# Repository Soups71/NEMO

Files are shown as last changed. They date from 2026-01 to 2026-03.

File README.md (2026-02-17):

# NEMO Documentation

Welcome to NEMO—the **NMEA2000 Education and Maritime Operations Platform**.

NEMO is a research platform for exploring at maritime network security. It simulates sensors, sniffs traffic, and demonstrates just how easy you can mess with NMEA2000.

This platform focuses on lowering the bar for getting started with boat hacking. Typically to get started with boat hacking you would need thousands of dollars worth of equipment or a friend with a boat. Thankfully, with NEMO all you need is about 40 dollars.

## What's In Here

### Getting Your Feet Wet
1. **[Project Overview](Documentation/README.md)** - What this is and why boats need better security
2. **[Getting Started](Documentation/Getting_Started.md)** - From zero to flashing firmware
3. **[Operations Guide](Documentation/Operations_Guide.md)** - How to actually use the thing
4. **[FAQ](Documentation/FAQ.md)** - "Why doesn't X work?" answered here

### Understanding the Protocols
1. **[NMEA2000 Protocol](Documentation/NMEA2000.md)** - The marine standard for device communication

### Hardware
1. **[Design Reference](Documentation/PCB_Design.md)** - Schematics, layout, gerbers
2. **[3-D Printed Case](Documentation/Case_Design.md)** - Documentation on the case

### Software
9. **[Source Code Architecture](Documentation/Source_Code_Architecture.md)** - Deep dive into the firmware

### The Fun Part
10. **[Security Research & Attacks](Documentation/Attacks.md)** - How the attacks work and academic context

## Quick Start (TL;DR)

1. Get parts from [Hardware Guide](Documentation/PCB_Design.md)
2. Flash firmware via [Getting Started](Documentation/Getting_Started.md)
3. Learn the UI in [Operations Guide](Documentation/Operations_Guide.md)
4. Break Stuff
5. Profit!

## What This Is For

NEMO exists for:
- **Security researchers** exploring maritime vulnerabilities
- **Students** learning about CAN bus and protocol weaknesses
- **Industry folks** who want to see why NMEA2000 security matters

## Contributing

Found a bug? Got a cool feature idea? Open an issue or send a PR.

Contribution Ideas:
- New PGN support
- Bug fixes
- Documentation improvements

## Contact

Any questions or concerns regarding this project can be sent to nemo@jamescampbell.org

## Disclaimer

Released for educational and research purposes. Don't do crimes with it.

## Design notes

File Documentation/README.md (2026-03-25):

# Project Overview

## What's NEMO?

NEMO (NMEA2000 Education and Maritime Operations platform) is a Teensy 4.0-based research platform that lets you simulate a boat network in the palm of your hand. Security researchers, students, and maritime folks can poke around and see how NMEA2000 actually works - and more importantly, how it breaks.

The device can:

- Pretend to be multiple marine sensors on an NMEA2000 network
- Sniff traffic from other devices on the bus
- Impersonate other devices on the CAN network
- Perform DOS attack that prevents all devices from communicating on the BUS.

Simply stated, you can hack a boat without actually having a boat.

## Why Build This?

Modern boats are basically networked computers floating on water. Most information such as Navigation, autopilot messages, depth readings, and more are sent over NMEA2000. This connectivity is great for interoperability but terrible for security.

Here's the problem: NMEA2000 was designed in the 90s and released in 2001 when "network security" meant securing the boat physically. There's no authentication, no encryption, and any device on the bus can say whatever it wants. This was to make it a cheap and versitle platform that enabled communication across manufacture and device.

However, One bad device can spoof sensor readings, steal addresses, or flood the network with garbage.

This project exists to:

1. **Show people** how these attacks actually work
2. **Give researchers** a platform for developing defenses
3. **Raise awareness** that maritime cybersecurity is a real problem

## The Big Picture

Ships are critical infrastructure. Cargo vessels move 90% of global trade. Ferries carry millions of people. Fishing boats feed communities. 

Researchers have shown attacks that could:

- Display fake GPS positions, sending vessels off course
- Manipulate depth readings, potentially causing groundings
- Hide engine problems, masking critical failures
- Confuse autopilots with conflicting commands

By making these vulnerabilities tangible, we're trying to push the industry toward actually fixing this stuff.

## Architecture

NEMO runs on a Teensy 4.0 with two independent CAN interfaces:

- **CAN1**: Handles the transmission of information on to the bus. This includes three fake NMEA2000 sensors, spoofed NMEA messages, and carries out the DOS attacks.
- **CAN2** : Listen-only mode for monitoring the network.

This dual-bus design lets you both participate in AND watch the network at the same time. Hook two NEMO devices together and one can play victim while the other demonstrates attacks.

For the full code breakdown, see [Source Code Architecture](Source_Code_Architecture.md).

### User Interface

The UI runs on a 1.3" SH1106 OLED (128x64 pixels) with four buttons:
- **Up/Down**: Navigate menus, change values
- **Left**: Go back, cancel
- **Right**: Select, confirm

Three 10K pots provide analog input for:
- Controlling fake sensor values
- Adjusting attack parameters on the fly

### What It Can Do

**Sensor Simulation** (13 types):

- Navigation: Heading, Depth, Speed, Position, COG/SOG
- Engine: RPM, Rudder Angle
- Environment: Wind, Temperature, Pressure, Humidity
- Systems: Battery Voltage, Tank Level

**Network Monitoring**:

- Auto-discovery via ISO Address Claim and Product Info
- Real-time PGN parsing and display
- Heartbeat-based stale device detection
- CAN Data Dump through serial interface

**Attack Demonstrations**:

- DOS Attack (Address Claim Takeover)
- Impersonation Attack (Data Spoofing with field locking)

**Data Dump**:

- All data that is received by the device is dumped out over the Serial Console in the standard CANDUMP format.
- This can then be processed by `candump2analyzer` and `analyzer` procided by the CANBOAT organization. [CANBOAT](https://github.com/canboat/canboat)

## Hardware Design

The custom PCB puts everything together. Check [PCB Design Reference](PCB_Design.md) for:

- Complete schematics
- Part specs and numbers
- Layout considerations
- Gerbers for manufacturing

## Credit

This project would not be possible without the amazing work put together by [Timo Lappalainen](https://github.com/ttlappalainen) and the people over at the [CANBOAT Project](https://github.com/canboat). They both have put in a ton of effort that has enabled this project. Please go check out their work if you're interested in Boat Hacking and NMEA2000.

## Where To Go From Here

- Learn about [NMEA2000](NMEA2000.md) protocols
- Check the [Hardware Guide](PCB_Design.md) for build instructions
- Follow [Getting Started](Getting_Started.md) to flash the firmware
- Dig into the [Source Code Architecture](Source_Code_Architecture.md) if you want to hack on it

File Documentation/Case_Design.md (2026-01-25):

# Case Design Reference

Apart from the electrical hardware, I also created a 3-D printed case for the PCB. This was to minimize the chance of accidental shorts when setting the device down.

The design files for this can be found in the `NEMO/Case_Design/*`

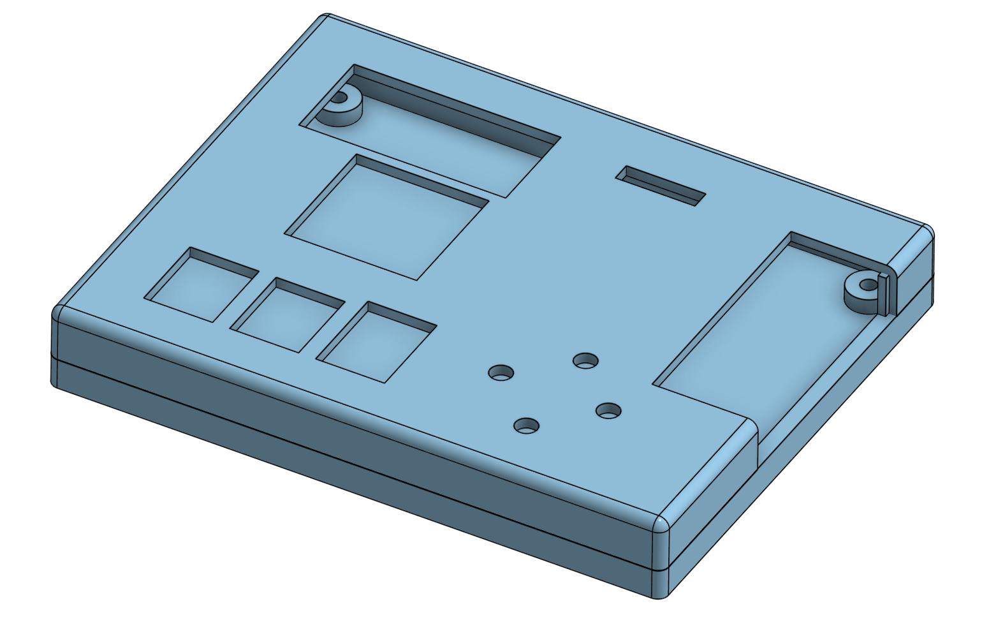
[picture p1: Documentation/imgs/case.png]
Case Design


## Files

### **Bottom.stl**

The bottom part of the case

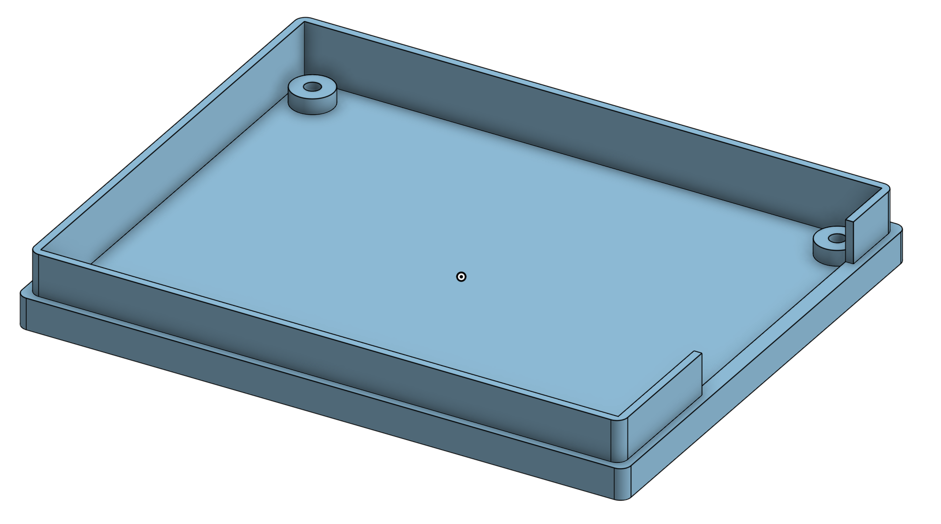
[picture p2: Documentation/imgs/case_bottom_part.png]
Bottom Part of the Case


### **Top.stl**

The top part of the case

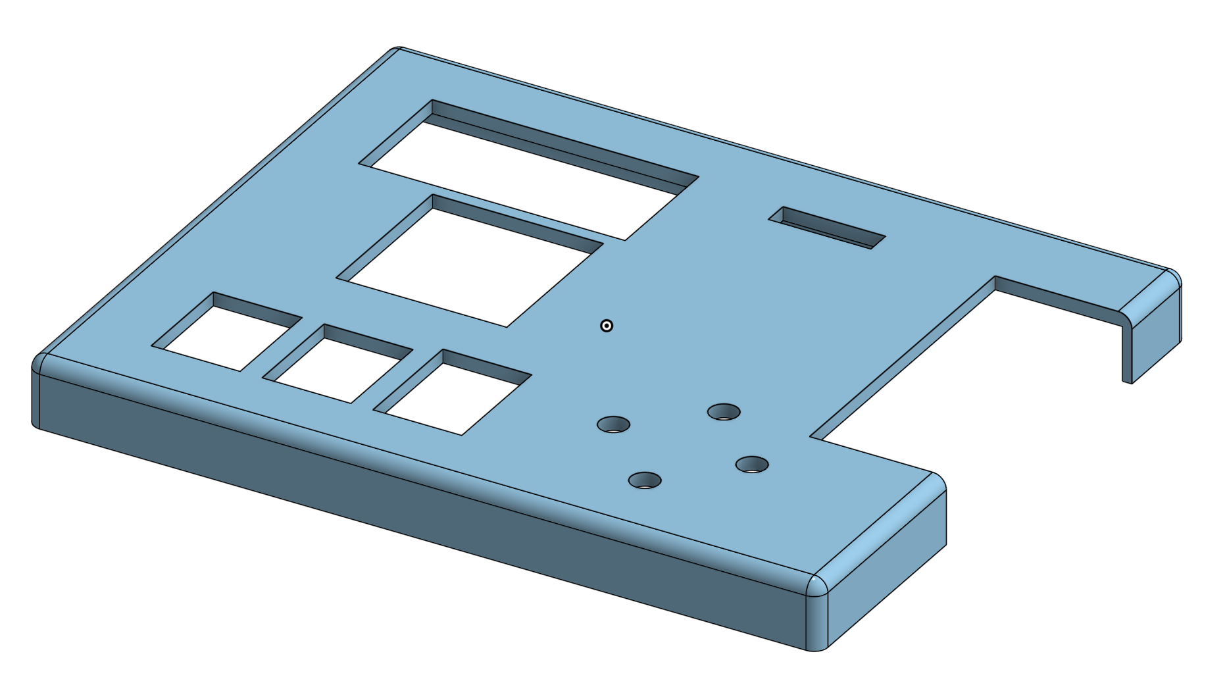
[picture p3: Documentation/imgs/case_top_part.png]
Top Part of the Case


## Printing

I printed both the top and bottom on my P1S and they turned out great with PLA+.

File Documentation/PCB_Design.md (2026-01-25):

# PCB Design Reference

So you want to build your own NEMO? Cool. This doc covers everything about the PCB including what's on it, why it's there, and how to not screw up the assembly.

If you don't want to go through the hassle of getting the PCB ordered or you don't want to use a Breadboard to build out the schematic you're in luck!

Email me at nemo@jamescampbell.org with "Board Request" as the subject and I will work with you to get a board shipped out.

## What We're Building

The NEMO PCB is a Teensy 4.0 shield that adds:
- Dual CAN bus interfaces (one for talking, one for snooping)
- OLED display for the UI
- D-pad buttons for navigation
- Three pots for controlling values
- NMEA2000 connector to plug into real networks

All the design files are KiCad 9.0 format in the `PCB/` folder.

## PCB Design

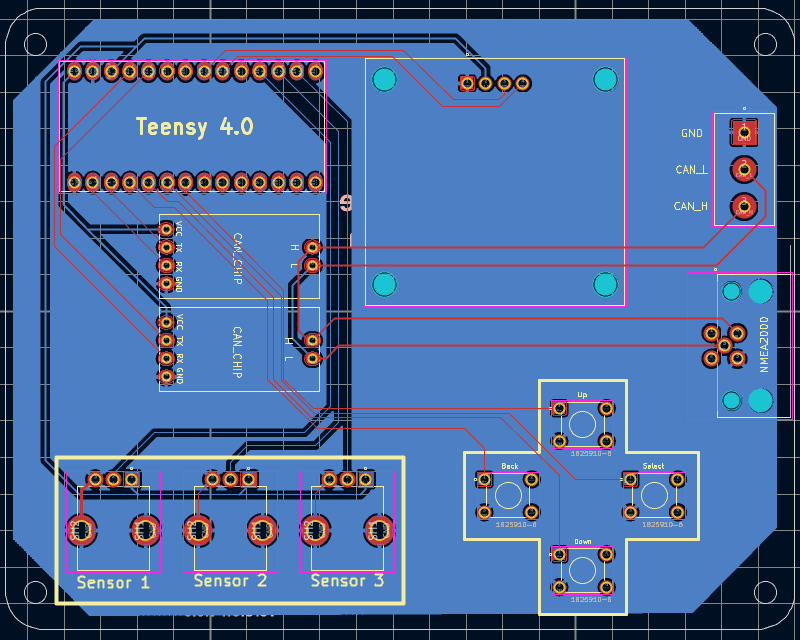
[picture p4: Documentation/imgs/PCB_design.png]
PCB Design


## Schematic

If you don't want to build the PCB from scratch, you can just use the schematic to build your own version.

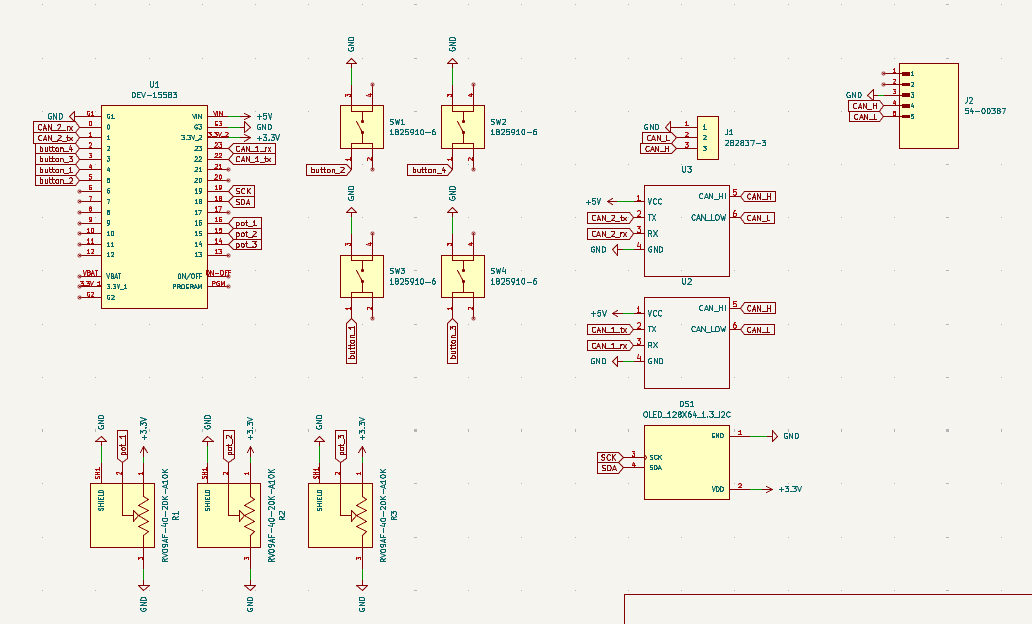
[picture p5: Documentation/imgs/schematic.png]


## Parts List

### Links to Amazon

Below are the links to the parts I used when building my prototypes and ultimately my final board. There are definetly cheaper options, but milage may vary

| | |
|-|-|
|Teensy 4.0|https://www.sparkfun.com/teensy-4-0.html|
|SH1106 Display|https://www.amazon.com/dp/B0C3L7N917|
|TJA1050|https://www.amazon.com/dp/B0C7ZBDG4B|
|10k Potentiometer| https://www.amazon.com/dp/B0DN1DHWLR|
|Buttons|https://www.amazon.com/dp/B07HB12V9Q|
|3 Screw Terminal|https://www.amazon.com/dp/B08PQG24YK|
|NMEA2000 Terminal|https://us.rs-online.com/product/rs-pro/2017209/72310500/|

**I do not guarentee quality from a supplier. These are just what worked for me.**

### The Brain: Teensy 4.0

| | |
|-|-|
| Part | SparkFun DEV-15583 |
| Chip | NXP iMXRT1062, ARM Cortex-M7 @ 600MHz |
| CAN | 2x FlexCAN controllers (this is why I picked it) |

**Pin Usage**:

| Pin | What | Why |
|-----|---|-----|
| 0 | CAN2_TX | Monitor bus TX (not really used in listen-only) |
| 1 | CAN2_RX | Monitor bus RX |
| 2 | button_1 | Left/Back |
| 3 | button_2 | Down |
| 4 | button_4 | Right/Select |
| 5 | button_3 | Up |
| 14 (A0) | pot_3 | Sensor 3 value |
| 15 (A1) | pot_2 | Sensor 2 value |
| 16 (A2) | pot_1 | Sensor 1 value |
| 18 | SDA | I2C data to display |
| 19 | SCL | I2C clock to display |
| 22 | CAN1_TX | Attack/transmit bus TX |
| 23 | CAN1_RX | Attack/transmit bus RX |

### CAN Transceivers

You need two of these - one for each CAN bus.

| | |
|-|-|
| Options | TJA1050 |
| Voltage | **5V** - this is important! |

**Wiring**:

| Pin | Function |
|-----|---|
| 1 | TXD (from Teensy) |
| 2 | GND |
| 3 | VCC (5V) |
| 4 | RXD (to Teensy) |
| 5 | CANL |
| 6 | CANH |

U2 = CAN1 (the attack bus)
U3 = CAN2 (the sniffer bus)

### Display

Just a 4-pin header: GND, VCC, SCL, SDA. Most modules have pull-ups built in.

Watch out! Some cheap displays have different pinouts. I made a mistake on the first prototype and burnt out a teensy. **Be Careful**

### Buttons

These are the D-pad:
- SW1 = Up (Pin 5)
- SW2 = Down (Pin 3)
- SW3 = Left (Pin 2)
- SW4 = Right (Pin 4)

Active low - one pin to GPIO, one pin to ground. Firmware enables internal pullups.

### Pots (R1-R3)

Wiring:
- Pin 1 (CCW end): GND
- Pin 2 (wiper): Teensy analog input
- Pin 3 (CW end): 3.3V

These control the sensor values and attack parameters. Turn the knob, change the data.

### NMEA2000 Connector

| | |
|-|-|
| Part | RS PRO 2017209 |
| Mates with | Standard NMEA2000 cables |

**Pinout** (standard NMEA2000):

| Pin | Color | Function |
|-----|---|---|
| 1 | White | Shield/GND |
| 2 | Blue | CAN_L |
| 3 | Black | GND |
| 4 | Red | +12V (optional power input) |
| 5 | White | CAN_H |

This connects to CAN2 (the sniffer). You can plug NEMO right into a boat's backbone.

### Terminal Block 

Alternative CAN connection for bench testing. CAN_H, CAN_L, GND.

## Power

### Where It Comes From

**USB** 
- Plug USB into the Teensy
- Teensy's regulator provides voltage to everything
- Simple, good for development

Okay, I get it. Powering the device via the NMEA2000 bus would be cool. There is probably a version 2 coming down the line with that capability. However, I wanted to make this project as beginner friendly as possible and built with only readily accessible consumer parts. As a result, it was a conscience decision not to connect power to the bus. I don't need someone blowing out their USB port because they left it plugged in while they also had it connected to the NMEA2000 network.

**CAN1**: This is where NEMO transmits messages. Fake sensors broadcast here, attacks go here.

**CAN2**: Listen-only mode. NEMO watches the network without participating in arbitration.

## Resources

- [Teensy 4.0 Pinout](https://www.pjrc.com/teensy/pinout.html)
- [NMEA2000 Physical Layer](https://www.nmea.org/)
- [KiCad Docs](https://docs.kicad.org/)

That's the hardware. Build it, flash it, plug it into a boat network, and have fun.

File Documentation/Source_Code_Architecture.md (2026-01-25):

# Source Code Architecture

Welcome to the guts of NEMO. This doc breaks down how the firmware works, what each module does, and where to find stuff when you want to hack on it yourself.

## Project Structure

We're using PlatformIO because fighting with Arduino IDE dependency hell isn't fun for anyone.

## Build Setup

**File**: `SRC/platformio.ini`

Nothing fancy here:

```ini
[env:teensy40]
platform = teensy
board = teensy40
framework = arduino
```

### Dependencies

| Library | What it does |
|---|---|
| `U8g2` | Talks to the OLED |
| `Adafruit SSD1306` | More display stuff |
| `Adafruit GFX Library` | Drawing primitives |
| `VEGA_SH1106` | Our specific display controller |
| `NMEA2000` | The protocol stack |
| `NMEA2000_Teensyx` | Teensy CAN driver |

The NMEA2000 libs are forked versions for stability. 

## The Main Loop (`main.cpp`)

**File**: `SRC/src/main.cpp`

### Pin Mapping

```cpp
// Pots for controlling values
#define SENSOR_1 16    // A2 - Pot R1
#define SENSOR_2 15    // A1 - Pot R2
#define SENSOR_3 14    // A0 - Pot R3

// D-pad buttons (active-low, pullups enabled)
#define BUTTON_UP 5
#define BUTTON_DOWN 3
#define BUTTON_LEFT 2
#define BUTTON_RIGHT 4
```

### The Dual-Bus Trick

The Teensy 4.0 has two easily accessible CAN controllers:

```cpp
tNMEA2000_Teensyx NMEA2000_CAN1(tNMEA2000_Teensyx::CAN1);  // TX bus
tNMEA2000_Teensyx NMEA2000_CAN2(tNMEA2000_Teensyx::CAN2);  // Sniffer bus
```

**Why two buses?**

- **CAN1**: This is transmits all messages on the bus, including three fake sensors, plus all the attack traffic.
- **CAN2** : Listen-only mode. NEMO sniffs everything without participating in arbitration - nobody knows we're watching.

You can be on the network AND monitor it at the same time. Pretty useful for seeing the effects of your attacks in real-time.

### Multi-Device Set-Up

```cpp
#define DEVICE_MANUFACTURER_CODE 2046  // Fake Manufacture Code by default
#define DEVICE_CLASS 25                 // "Inter/Intranetwork Device"
#define NUM_DEVICES 3                   // Three fake devices
```

Each sensor is a fully independent NMEA2000 device with its own:
- Source address
- 64-bit NAME 
- Product info (model name, serial, version)
- Heartbeat

### Boot Sequence

When `setup()` runs:

1. Serial at 115200 for debug output
2. Configure all the pins
3. Spin up CAN1 with three devices starting at address 22
4. Spin up CAN2 in sniff mode with a fat 2048-frame buffer
5. Init the OLED
6. Create the monitor, attack controller, and menu controller
7. Show the main menu

### Debug Output

Everything received on CAN2 gets dumped in `candump` format:

```
can1  09F80106   [8]  00 00 23 FF FF FF FF FF
can1  09F11001   [8]  01 18 27 4A 00 FF 64 00
```

Hook up a terminal at 115200 baud and you can pipe this to analysis tools. Fast-packet messages get reassembled so you see the original frames.

## Constants (`constants.h`)

**File**: `SRC/include/constants.h`

This is where all the tunables live. Mess with these to change behavior without touching logic.

### Debug Flag

```cpp
#define DEBUG false  // true = verbose, false = candump only
```

### Timing

```cpp
STALE_TIMEOUT_MS = 60000   // Remove devices after 1 min silence
SCROLL_DELAY_MS = 400      // Text scroll speed
MAX_IMP_FIELDS = 16        // Max fields you can lock during impersonate
```

## Sensor Types

13 different sensors you can simulate:

| # | Type | PGN | Range |
|---|---|-----|---|
| 0 | Engine RPM | 127488 | 0-6000 |
| 1 | Water Depth | 128267 | 0-100m |
| 2 | Heading | 127250 | 0-360° |
| 3 | Speed | 128259 | 0-20 knots |
| 4 | Rudder | 127245 | ±45° |
| 5 | Wind Speed | 130306 | 0-50 m/s |
| 6 | Wind Angle | 130306 | 0-360° |
| 7 | Water Temp | 130311 | -5 to 40°C |
| 8 | Outside Temp | 130310 | -20 to 50°C |
| 9 | Pressure | 130314 | 80-110 kPa |
| 10 | Humidity | 130313 | 0-100% |
| 11 | Battery | 127508 | 0-30V |
| 12 | Tank Level | 127505 | 0-100% |

## Fake Manufacturer IDs

Want to pretend you're Garmin? Raymarine?

| Manufacturer | Code |
|---|---|
| Garmin | 229 |
| Raymarine | 1851 |
| Simrad | 1857 |
| Navico | 275 |
| Lowrance | 140 |
| Furuno | 1855 |
| B&G | 381 |
| Mercury | 144 |
| Yamaha | 1862 |
| Volvo Penta | 174 |
| Maretron | 137 |

## Spoofable PGNs

28 message types NEMO can impersonate - basically anything useful for navigation, engine monitoring, or environmental data:

```cpp
127245 (Rudder), 127250 (Heading), 127251 (Rate of Turn),
127252 (Heave), 127257 (Attitude), 127258 (Mag Variation),
127488 (Engine Rapid), 127489 (Engine Dynamic), 127493 (Transmission),
127497 (Trip Fuel), 127505 (Fluid Level), 127506 (DC Status),
127507 (Charger), 127508 (Battery), 128000 (Leeway),
128259 (Speed Water), 128267 (Depth), 129025 (Position),
129026 (COG/SOG), 130306 (Wind), 130310-130316 (Environmental),
130576 (Trim Tab), 130577 (Direction)
```

## Debugging Tips

Serial output at 115200 shows all sniffed traffic in candump format. Pipe it to your favorite analysis tools.

| Problem | Likely Cause | Fix |
|---|---|-----|
| No serial | Wrong baud | Set to 115200 |
| Black screen | I2C wiring | Check SDA(18), SCL(19) |
| No CAN traffic | Missing termination | Add 120 ohm resistors |
| Sensors not broadcasting | Inactive | Enable in Configure menu |

That's the architecture. Go hack some boats (in a lab enviroment, with your own equipment, obviously).

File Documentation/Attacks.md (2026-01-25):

# Security Research and Attack Demos

This doc covers the attacks NEMO can demonstrate, how they work under the hood, and what they would mean on a real boat.

## The Two Attacks

NEMO implements two attack categories:

1. **DOS Attack** - Kicks all devices off the network
2. **Impersonation Attack** - Spoofs valid sensors on the network by modifying fields certain fields and leaving others alone

Both exploit fundamental weaknesses in how NMEA2000 trusts devices on the bus - inherited straight from CAN and ISO 11783.

## DOS Attack

### The Gist

Every NMEA2000 device has a 64-bit NAME that determines its priority in address fights. When two devices claim the same address, the one with the numerically lower NAME wins. Loser has to find a new address or go dark.

NEMO's attack exploits this by:

1. **Building a high-priority NAME** with artificially low values
2. **Claiming all possible addresses** with the superior NAME. This forces all devices to find a new address.
3. **Continuosly override address claims** of the other devices as they try to find a new valid address.

The attack NAME uses:
- Unique Number: 0 (lowest possible)
- Manufacturer Code: 0 (lowest possible)
- Priority: 0 (Highest priority)
- Everything else minimized

This creates a NAME that beats basically any real device.

### What Happens

When a device loses its address claim, it has to either:
- Find an unclaimed address
- Go offline

On an actual boat this could mean:
- GPS/chartplotter stops updating
- Depth sounder data disappears
- Engine monitoring goes away
- Autopilot loses its inputs

## Impersonation Attack (Data Spoofing)

### The Gist

NMEA2000 has zero authentication. Any device can send any PGN from any source address. The impersonation attack:

1. **Monitors traffic** to see legitimate sensor data
2. **Picks a target** device and the PGNs it transmits
3. **Replays modified messages** with our own values
4. **Uses the potentiometer** to control spoofed values in real time

NEMO copies the message structure but swaps in whatever values the user wants.

### Supported PGNs

NEMO can spoof these:

**Navigation:**
- 127250: Vessel Heading
- 129025: Position (Lat/Long)
- 129026: COG/SOG
- 128267: Water Depth

**Engine & Systems:**
- 127488: Engine RPM
- 127489: Engine Parameters (oil pressure, temp, etc.)
- 127505: Fluid Level (fuel tanks)
- 127508: Battery Status

**Environmental:**
- 130306: Wind Data
- 130310/130311: Environmental Parameters
- 130312: Temperature
- 130314: Pressure

### What Could Go Wrong

**Fake Position Data**
Spoofing PGN 129025 (Position) or 129026 (COG/SOG):
- Chartplotter shows wrong location
- AIS broadcasts lies to other vessels
- Autopilot navigates to the wrong place
- ECDIS route monitoring fails

**Manipulated Depth**
Spoofing PGN 128267 (Water Depth):
- Show deeper water than reality → grounding risk
- Show shallower water → unnecessary course changes
- Disable shallow water alarms

**False Engine Data**
Spoofing engine PGNs:
- Hide overheating or low oil pressure
- Show fake RPM
- Mask critical failures until it's too late

**Wrong Wind Data**
Spoofing PGN 130306 (Wind Data):
- Mess up sail trim systems
- Make autopilot wind-steering go haywire
- Mislead crew about conditions

### Why Not Just Spoof Another Sensor?

Devices such as displays and autopilots often require the configuration of devices to ensure that the information displayed is from the correct device.

This means that if an attacker were to just send information on the bus the chance that it would actually be displayed by smart displays is actually pretty low.

By spoofing a device that is alreay on the network, it increases the chances that our modified values will actually appear on displays and be processed by autopilots.

-- 

## References

These attacks are not novel and have been well documented in other fields. Here are some articles that aided in the design of the attacks.

https://www.can-cia.org/fileadmin/cia/documents/publications/cnlm/june_2023/cnlm_23-2_p28_j1939-based_networks_vulnerability_to_address_claim_hunter_cyberattack_chri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

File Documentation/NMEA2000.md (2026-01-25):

# NMEA2000 Protocol

## What's NMEA2000?

NMEA2000 (also written N2K) is the communication standard that boats use for connecting sensors, displays, and control systems. Think of it as the marine equivalent of your car's internal network - it lets the GPS talk to the chartplotter, the depth sounder share data with the autopilot, and the engine computer report status to the helm display.

The protocol comes from the National Marine Electronics Association (NMEA), the same organization behind the older NMEA 0183 standard.

## NMEA 0183 vs NMEA2000

If you've messed with marine electronics before, you probably hit NMEA 0183 first. It spits out human-readable sentences like:

```
$GPGGA,123519,4807.038,N,01131.000,E,1,08,0.9,545.4,M,47.0,M,,*47
```

0183 worked fine for decades, but it's got issues:
- Slow (4,800 baud, sometimes 38,400)
- Point-to-point wiring
- No standard connector
- ASCII text only

NMEA2000 fixes these:

| Thing | NMEA 0183 | NMEA2000 |
|---|---|---|
| Speed | 4,800-38,400 baud | 250,000 baud |
| Topology | Point-to-point | Multi-drop bus |
| Connector | Whatever | Standardized 5-pin connector |
| Format | ASCII text | Binary |
| Power | Separate | On the network cable |

## Under the Hood

NMEA2000 is built on existing standards:

1. **Physical Layer**: CAN bus at 250 kbps
2. **Data Link Layer**: ISO 11783-3 (also used in tractors, fun fact)
3. **Network Layer**: ISO 11783-5 for address management
4. **Application Layer**: NMEA's Parameter Group Numbers (PGNs)

This means NMEA2000 devices use off-the-shelf CAN chips. The interesting stuff is in the protocol on top.

## Addressing and Identity

Every device needs a unique source address (0-251). But addresses aren't hardcoded - NMEA2000 uses dynamic claiming based on ISO 11783.

Each device has a 64-bit NAME that uniquely identifies it:

| Field | Bits | What |
|---|---|---|
| Identity Number | 21 | Serial number from manufacturer |
| Manufacturer Code | 11 | Assigned by NMEA |
| Device Instance | 3 | Distinguishes multiples of same device |
| Device Function | 8 | What it does |
| Device Class | 7 | Category |
| System Instance | 4 | For complex installs |
| Industry Group | 3 | Marine = 4 |
| Self-Configurable | 1 | Always 1 for N2K |

When a device powers on, it broadcasts its NAME to claim an address using the 60928 PGN. If two devices want the same address, the one with the numerically lower NAME wins. Loser picks a different address.

**This is the key to the DOS attack**: NAME determines priority. A device with a lower NAME can kick any higher-NAME device off its address.

## Parameter Group Numbers (PGNs)

Data in NMEA2000 comes in Parameter Groups, each with a PGN. Think of PGNs as message types. Common ones:

| PGN | Name | What It Carries |
|-----|---|---|
| 60928 | ISO Address Claim | Device identity broadcast |
| 126992 | System Time | Date and time |
| 127250 | Vessel Heading | Compass heading |
| 127488 | Engine Parameters, Rapid | RPM, boost pressure |
| 128259 | Speed, Water Referenced | Speed through water |
| 128267 | Water Depth | Depth below transducer |
| 129025 | Position, Rapid Update | Lat/long |
| 129026 | COG & SOG | Course and speed over ground |
| 130306 | Wind Data | Wind speed and angle |

NMEA sells the complete PGN database, but many common ones are documented through reverse engineering and the open source library community.

Shoutout to CANBOAT project for doing a ton of the heavy lifting. Check them out here: [CANBOAT](https://canboat.github.io/canboat/canboat.html)

## Message Structure

NMEA2000 packs data into CAN frames. The 29-bit identifier encodes:

- Priority (3 bits): 0-7, lower = higher priority
- PGN (18 bits): The parameter group number
- Source Address (8 bits): Who sent it

Data fields use standardized formats:
- Temperatures in 0.01 Kelvin
- Angles in radians × 10,000
- Distances in 0.01 meters
- Speed in 0.01 m/s

The library handles conversions, but knowing raw formats helps when analyzing traffic.

## Fast Packets

Some data doesn't fit in 8 bytes. For these, NMEA2000 uses "fast packet" messages spanning multiple frames. 

Fast packets include sequence and frame counters so receivers can reassemble the complete message.

## Network Layout

A typical network consists of all of devices connecting to one backbone. 

The backbone is a trunk cable with T-connectors for each device. Termination resistors cap each end. Power can flow through the network or come in separately for hungry devices.

Max length is around 100 meters for the backbone with 6-meter drops.

## The Security Problem

NMEA2000 inherits CAN's trust model: any device can send any message. Combined with address claiming, this creates attack vectors:

1. **Spoofing**: Send fake sensor data (false GPS, wrong depth)
2. **Denial of Service**: Flood the bus with high-priority garbage
3. **Impersonation**: Pretend to be a specific device

There's no cryptographic authentication. A device can't verify that a message actually came from the claimed source. No integrity protection beyond basic CRC error checking.

This wasn't an oversight - it reflects the threat model of the 90s when the protocol was designed. "Network security" meant physical access control: only trusted devices get plugged in.

That assumption increasingly fails as:
- WiFi gateways get added for monitoring
- USB and Bluetooth adapters provide diagnostic access
- Aftermarket devices from sketchy sources get installed
- Charter boats have random users

## NEMO Implementation

NEMO implements NMEA2000 using the Teensy 4.0's dual FlexCAN controllers and the NMEA2000 library. Here's how it all fits together.

### Multi-Device Mode

NEMO simulates up to three independent NMEA2000 devices on CAN1. Each gets its own:
- Source address (starting at 22)
- Device NAME (64-bit unique ID)
- Product information
- Heartbeat interval

### Supported PGNs

NEMO generates and parses these (defined in `constants.h`):

| PGN | Name | NEMO Use |
|-----|---|---|
| 60928 | ISO Address Claim | Identity, attack target |
| 126993 | Heartbeat | Device presence |
| 126996 | Product Information | Name extraction |
| 127245 | Rudder | Simulate/spoof |
| 127250 | Vessel Heading | Simulate/spoof |
| 127488 | Engine RPM | Simulate/spoof |
| 127489 | Engine Parameters | Spoof only |
| 127505 | Fluid Level | Simulate/spoof |
| 127508 | Battery Status | Simulate/spoof |
| 128259 | Speed, Water | Simulate/spoof |
| 128267 | Water Depth | Simulate/spoof |
| 129025 | Position | Spoof only |
| 129026 | COG & SOG | Spoof only |
| 130306 | Wind Data | Simulate/spoof |
| 130310-130316 | Environmental | Simulate/spoof |

For the full code breakdown, see [Source Code Architecture](Source_Code_Architecture.md).

## More Reading

- [NMEA 2000 Explained](https://www.nmea.org/nmea-2000.html) - Official NMEA overview
- [OpenSkipper NMEA2000 Documentation](http://openskipper.org/) - Open source notes
- [CANboat](https://github.com/canboat/canboat) - PGN docs and analysis tools
- [NMEA2000 Library](https://github.com/ttlappalainen/NMEA2000) - The NMEA2000 Library used
- [Full NMEA2000 Breakdown](https://www.csselectronics.com/pages/nmea-2000-n2k-intro-tutorial)

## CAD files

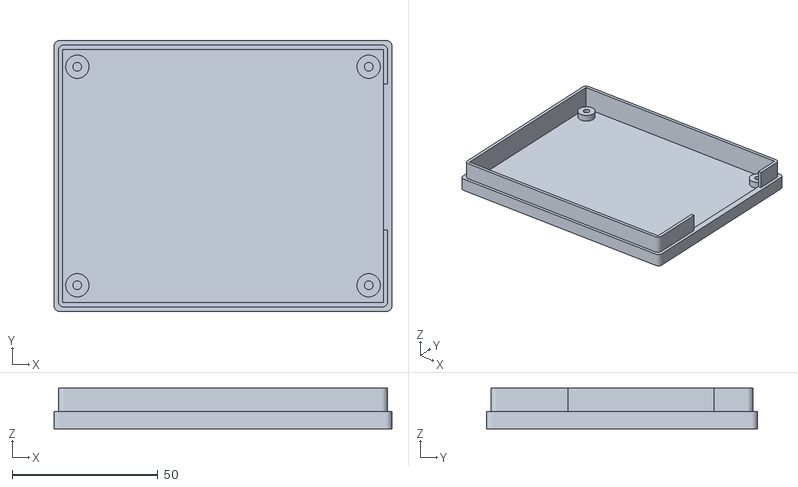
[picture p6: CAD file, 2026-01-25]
Case_Design/Bottom.stl
116.0 x 93.0 x 14.0

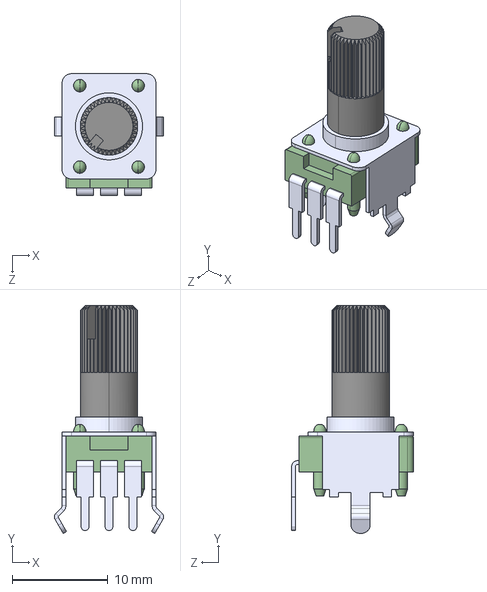
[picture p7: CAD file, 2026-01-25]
PCB/RV09AF-40-20K-A10K/RV09AF-40-20K-A10K.step
11.4 x 23.8 x 12.7 mm

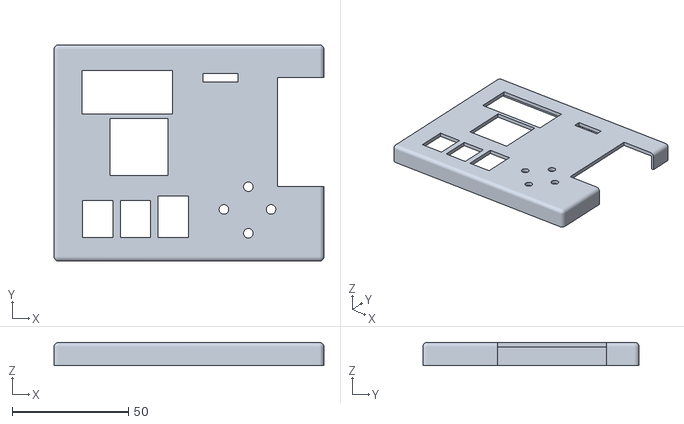
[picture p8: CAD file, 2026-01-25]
Case_Design/Top.stl
116.0 x 93.0 x 10.0

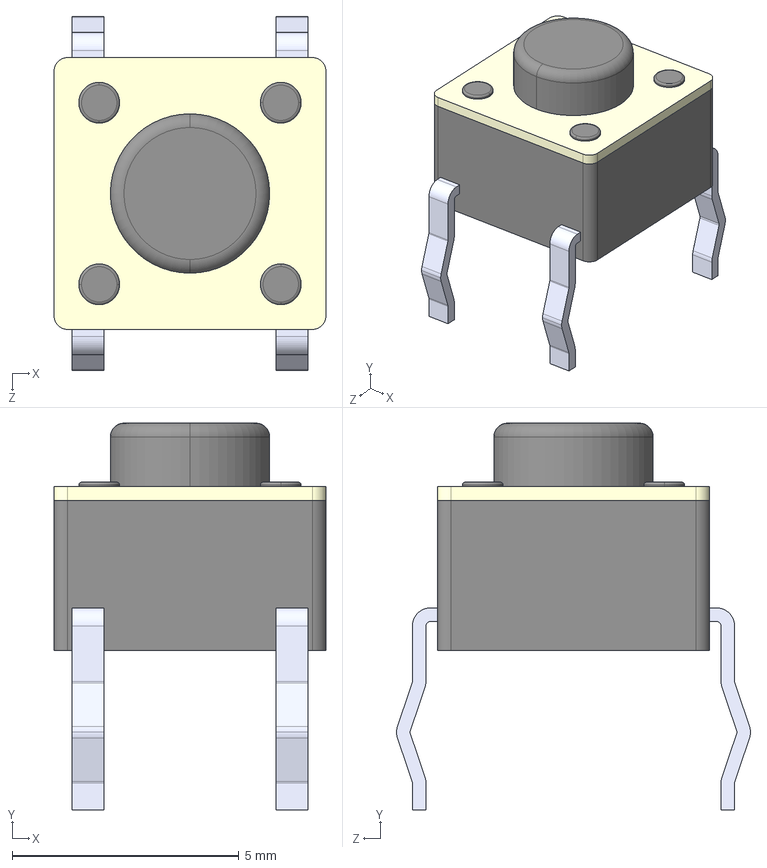
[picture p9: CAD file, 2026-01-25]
PCB/1825910-6/1825910-6.step
5.99 x 8.52 x 7.80 mm

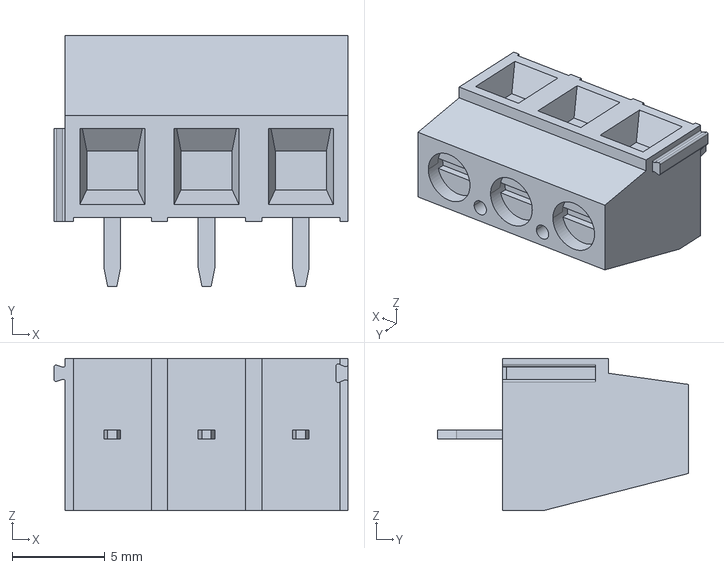
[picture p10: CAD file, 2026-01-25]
PCB/3_pin_terminal_block/282837-3.step
15.8 x 13.5 x 8.20 mm

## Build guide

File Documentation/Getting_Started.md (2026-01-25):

# Getting Started

Let's get your NEMO up and running. This guide covers setting up your dev environment and flashing the firmware.

## What You Need

- Computer with USB (Windows, macOS, or Linux)
- NEMO (see [Hardware Guide](PCB_Design.md))
- Micro USB cable for programming

## Step 1: Install PlatformIO

PlatformIO is used for building and uploading. Pick your flavor:

### VS Code Extension (Recommended)

1. Get [Visual Studio Code](https://code.visualstudio.com/)
2. Open VS Code, go to Extensions (Ctrl+Shift+X / Cmd+Shift+X)
3. Search "PlatformIO IDE"
4. Install it
5. Wait for it to finish downloading (few minutes)
6. Restart VS Code

## Step 2: Install Teensy Tools

The Teensy needs its own uploader tool:

1. Grab Teensyduino from [PJRC's site](https://www.pjrc.com/teensy/teensyduino.html)
2. Run the installer
3. When it asks about Arduino, you can skip that.

The Teensy Loader app is what actually pushes firmware to the board.

## Step 3: Get the Code

Clone it:

```bash
git clone https://github.com/Soups71/NEMO.git
cd NEMO
```

## Step 4: Open the Project

### VS Code + PlatformIO

1. Open VS Code
2. File → Open Folder
3. Navigate to `NEMO/SRC` (the firmware folder) and open it
4. Wait for PlatformIO to initialize (first time is slow)

You should see the PlatformIO toolbar at the bottom.

**Important**: Open `SRC` specifically, not the parent `NEMO` folder. PlatformIO needs `platformio.ini` in the root.

### Command Line

```bash
cd /path/to/NEMO/SRC
```

## Step 5: Build

Click the checkmark in the PlatformIO toolbar, or:
- Windows/Linux: Ctrl+Alt+B
- macOS: Cmd+Alt+B

Or use the PlatformIO sidebar (alien head icon) → Build.

First build takes a while - it's downloading libraries and toolchains. After that it's fast.

## Step 6: Upload

### VS Code

Connect the Teensy to your computer.

Click the arrow in the PlatformIO toolbar, or:
- Windows/Linux: Ctrl+Alt+U
- macOS: Cmd+Alt+U

### What Happens

1. PlatformIO builds if needed
2. Teensy Loader receives the hex file
3. If the Teensy is running old firmware, you might need to press its physical button to enter bootloader
4. Loader programs the device and reboots it

## Step 7: Check It Works

After upload:

1. OLED should light up with the main menu
2. Buttons should navigate
3. See [Operations Guide](Operations_Guide.md) for how to use everything

If display stays dark:
- Check I2C wiring
- Verify display power
- Try the reset button on Teensy

## Serial Monitor

For debugging, watch the serial output:

### VS Code

Click the plug icon in PlatformIO toolbar.

## Troubleshooting

### "No Teensy detected"

- USB cable might be charge-only (need data)
- Try different USB port
- Linux: might need udev rules for Teensy
- Press the button on the Teensy to force bootloader

### Build Fails

- Nuke the `.pio` folder and rebuild
- Update PlatformIO
- Check library downloads completed

### Upload Times Out

- Press the Teensy button during upload
- Make sure Teensy Loader is running
- Close anything else using the serial port

### Display Shows Garbage

- Wrong controller? Need SH1106, not SSD1306
- Some displays use 0x3D instead of 0x3C address
- Check for loose wires

## What's Next?

- [Operations Guide](Operations_Guide.md) - Step-by-step instructions for sensors, monitoring, and attacks
- [Attacks](Attacks.md) - See what NEMO can demonstrate
- Hook up two devices for the full attack demo experience

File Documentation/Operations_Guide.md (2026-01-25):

# Operations Guide

Step-by-step instructions for performing each NEMO operation from a fresh device boot.

**Prerequisites**: NEMO hardware is assembled and firmware is flashed. See [Getting Started](Getting_Started.md) if you haven't done this yet.

## 1. Simulate a Network Sensor

This configures NEMO to act as a fake NMEA2000 sensor that broadcasts data on the CAN bus.

### Hardware Setup

1. Connect NMEO to the NMEA2000 network
2. Ensure 120 ohm termination resistors are at each end of the CAN bus
3. Power on NEMO via USB 
   
### Steps from Fresh Boot

1. **Power on** - OLED displays the main menu:
   ```
       MAIN MENU

   > Sensor Readings
     Configure
     Attacks
     About
   ```

2. **Navigate to Configure** - Press **Down** once to highlight "Configure", then press **Right** to enter

3. **Select a Sensor** - You'll see:
   ```
      CONFIGURE

   > Sensor 1
     Sensor 2
     Sensor 3
     Device Config
   ```
   Press **Right** to configure Sensor 1 (or navigate to Sensor 2/3)

4. **Set Manufacturer** - The first field is "Manufacturer"
   - Press **Right** to edit
   - Use **Up/Down** to select: Garmin, Raymarine, Simrad, Navico, Lowrance, Furuno, B&G, Mercury, Yamaha, Volvo Penta, or Maretron
   - Press **Right** to confirm

5. **Set Device Type** - You're now on "Device Type"
   - Use **Up/Down** to select the sensor type you want to simulate:
     - Engine RPM (PGN 127488, range 0-6000 RPM)
     - Water Depth (PGN 128267, range 0-100m)
     - Heading (PGN 127250, range 0-360 degrees)
     - Speed (PGN 128259, range 0-20 m/s)
     - Rudder (PGN 127245, range -45 to +45 degrees)
     - Wind Speed (PGN 130306, range 0-50 m/s)
     - Wind Angle (PGN 130306, range 0-360 degrees)
     - Water Temp (PGN 130311, range -5 to +40 C)
     - Outside Temp (PGN 130310, range -20 to +50 C)
     - Pressure (PGN 130314, range 80-110 kPa)
     - Humidity (PGN 130313, range 0-100%)
     - Battery Voltage (PGN 127508, range 0-30V)
     - Tank Level (PGN 127505, range 0-100%)
   - Press **Right** to confirm

6. **Activate the Sensor** - You're now on "Active"
   - Press **Right** to toggel between "Yes" and "No"

7. **Control Sensor Value** - Turn the corresponding potentiometer to change the sensor's output value:
   - **Sensor 1**: Pot R1
   - **Sensor 2**: Pot R2
   - **Sensor 3**: Pot R3

8. **Exit** - Press **Left** repeatedly to return to the main menu

The sensor is now broadcasting NMEA2000 messages on CAN1. You can configure up to 3 independent sensors simultaneously.

## 2. View Live Data on the Network

This monitors NMEA2000 traffic and displays parsed sensor data in real-time.

### Hardware Setup

1. Connect NMEO to the NMEA2000 network
2. Ensure 120 ohm termination resistors are at each end of the CAN bus
3. Power on NEMO via USB

### Steps from Fresh Boot

1. **Power on** - OLED displays the main menu

2. **Enter Live Data** - "Live Data" is already highlighted, press **Right** to enter

3. **View Discovered Devices** - After a moment, you'll see devices on the network:
   ```
   Live Daya

   > Sensor 1 [22]
     GPS Unit [50]
     Depth Sounder [51]
   ```
   - Device name shown with source address in brackets
   - Use **Up/Down** to scroll through devices
   - Devices auto-appear when they send ISO Address Claims

4. **Select a Device** - Press **Right** on a device to see its details:
   ```
   Device: GPS Unit
   Addr: 50

   > 129025 Position
     129026 COG/SOG
     60928  Addr Claim
   ```

5. **View PGN Data** - Press **Right** on a PGN to see parsed fields:
   ```
    129025 Position

    Latitude: 42.3601
    Longitude: -71.0589
   ```
   Values update in real-time as new messages arrive

6. **Navigate Back** - Press **Left** to go back to device list or main menu

### Troubleshooting

- **No devices showing**: Check wiring, termination, and that devices are actually transmitting
- **Stale devices**: Devices disappear after 60 seconds of silence (configurable in Device Config)

## 3. Run an Impersonation Attack

This spoofs a legitimate device's messages by sending modified NMEA2000 data from its source address.

### Hardware Setup

1. Connect NMEO to the NMEA2000 network
2. Ensure 120 ohm termination resistors are at each end of the CAN bus
3. Power on NEMO via USB

### Steps from Fresh Boot

1. **Power on** - OLED displays the main menu

2. **Wait for Device Discovery** - Give NEMO a few seconds to discover devices. You can verify by checking "Live Data" first.

3. **Navigate to Attacks** - Press **Down** twice to highlight "Attacks", then press **Right**

4. **Select Impersonate** - You'll see:
   ```
       ATTACKS

   > DOS Attack
     Impersonate
   ```
   Press **Down** to highlight "Impersonate", then press **Right**

5. **Select Target Device** - A list of devices with impersonatable PGNs appears:
   ```
   SELECT TARGET

   > GPS Unit [50]
     Depth Sounder [51]
     Sensor 1 [22]
   ```
   - Only devices sending supported PGNs are shown
   - Use **Up/Down** to select, press **Right** to confirm

6. **Select Target PGN** - Choose which message type to spoof:
   ```
   SELECT PGN

   > 129025 Position
     129026 COG/SOG
   ```
   Press **Right** to confirm

7. **Select Field to Manipulate** - Choose which data field to control:
   ```
   SELECT FIELD

   > Latitude
     Longitude
   ```
   Press **Right** to confirm

8. **Adjust Value** - The attack is now active:
   ```
      IMPERSONATE

    Device: GPS Unit
    PGN: 129025 Position

    Latitude: 42.3601

    Pot: 42.3601
   ```
   - Turn **Pot R1** (Pin 16) to change the spoofed value
   - The display shows the current value and range

9. **Lock Field Value** (Optional) - Press **Right** to lock the current value:
   - The field now shows `[Locked]` prefix
   - You can select another field to manipulate
   - Locked fields maintain their value while you adjust others
   - You can lock up to 16 fields simultaneously

10. **Stop Attack** - Press **Left** to exit the menu. You will see "Attack Active" on the bottom. To check on the status, enter the attacks menu again. You will have the opprotunity to stop the attack or just view the current status.

### Example: Spoofing Position Data

1. Target: GPS Unit
2. PGN: 129025 (Position)
3. Lock Latitude at desired value (e.g., 42.3601)
4. Select Longitude field
5. Lock Longitude at desired value (e.g., -71.0589)
6. All connected chartplotters now display the fake position

## 4. Run a DOS Attack

This attack kicks devices off the network by winning all address arbitration fights.

### Hardware Setup

1. Connect NMEO to the NMEA2000 network
2. Ensure 120 ohm termination resistors are at each end of the CAN bus
3. Power on NEMO via USB

### Steps from Fresh Boot

1. **Power on** - OLED displays the main menu

2. **Navigate to Attacks** - Press **Down** twice to highlight "Attacks", then press **Right**

3. **Select Address Claim** - "DOS Attack" is already highlighted:
   ```
       ATTACKS

   > DOS Attack
     Impersonate
   ```
   Press **Right** to start

4. **Attack Begins Immediately** - The display shows:
   ```
     DOS Attack

    Status: ACTIVE
    Messages: 0

    Press < to stop
   ```
   - **Messages**: Counter increments as claims are sent
   - **Target**: Current address being claimed
   - Attack cycles through addresses 1-252

5. **Observe Effects** - Devices on the network will:
   - Lose their address claims
   - Attempt to find new addresses
   - Eventually go offline or become unresponsive
   - GPS, depth sounders, engine monitors all stop working

6. **Stop Attack** - Press **Left** to return to main menu:
   - "Attack Active" shows on the main menu
   - Enter the attack menu again to view attack status.
   - Press **Select** to stop the DOS attacl

### How It Works

NEMO sends ISO Address Claims (PGN 60928) with a high-priority NAME:
- Unique Number: 0 (lowest possible)
- Manufacturer Code: 0 (lowest possible)
- All priority fields minimized

This NAME beats any legitimate device in arbitration, forcing them off the bus.

## 5. Run Attack + Sensor Simultaneously

This demonstrates attack effects by running sensors and attacks together so you can see real-time impact.

### Hardware Setup: 

1. Power on NEMO via USB

### Steps from Fresh Boot

#### On NEMO:

1. **Power on**

2. **Configure Sensors** - Go to Configure > Sensor 2:
   - Set Manufacturer: Garmin (or any)
   - Set Device Type: Water Depth
   - Set Active: YES

3. **Configure Second Sensor** - Go to Configure > Sensor 3:
   - Set Manufacturer: Raymarine (or any)
   - Set Device Type: Heading
   - Set Active: YES

4. **Return to Main Menu** - Press **Left** until you're at the main menu

5. **Open Live Data** - Press **Right** on "Live Data" to monitor your own sensors

6. **Return to Main Menu** - Press **Left**

7. **Launch Impersonation Attack**:
   - Go to Attacks > Impersonate
   - Select "Sensor 2" or "Sensor 3"
   - Select PGN 128267 (Water Depth)
   - Select "Depth" field
   - Turn potentiometer on Sensor 1 to set a fake depth value.
   - Lock the value in and return to main menu.

#### Observe the Effect:

- Watch Live Data > Sensor 2 > PGN 128267
- The depth value will flicker between:
  - Real value (Sensor 2)
  - Spoofed value (Sensor 1 value)

### DOS Attack Demo

1. Configure and activate sensors 1, 2, and 3

2. Launch DOS attack (Attacks > DOS Attack)

3. Return to "Live Data" menu:
   - Sensors disappear from Sensor Readings
   - Network becomes unusable
   - Device names may flicker as they fight for addresses

4. **Stop Attack**

5. **Watch Recovery**:
   - Sensors reappear after a few seconds
   - Normal operation resumes

## Quick Reference

| Operation | Menu Path | Key Controls |
|---|---|---|
| Simulate Sensor | Configure > Sensor 1/2/3 | Pot controls value |
| View Live Data | Sensor Readings | Up/Down scroll, Right to drill down |
| Impersonate | Attacks > Impersonate | Pot controls spoofed value, Right locks |
| DOS Attack | Attacks > DOS Attack | Starts immediately|

## Button Reference

| Button | Function |
|---|---|
| **Up** | Navigate up / Increase value |
| **Down** | Navigate down / Decrease value |
| **Left** | Go back / Stop attack |
| **Right** | Select / Confirm / Lock field |

## Potentiometer Assignment

| Potentiometer | Pin | Controls |
|---|-----|---|
| Pot R1 | 16 | Sensor 1 value / Attack field value |
| Pot R2 | 15 | Sensor 2 value |
| Pot R3 | 14 | Sensor 3 value |

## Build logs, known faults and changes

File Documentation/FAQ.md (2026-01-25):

# Frequently Asked Questions

Got questions? We've got answers. And probably some sarcastic remarks.

## General Stuff

### What does NEMO stand for?

NMEA2000 Education and Maritime Operations platform.

### Do I need two devices?

No!

This device is designed to be self contained meaning that you can simulate and entire's boat network with just one device.

You can simulate sensors while simultaneously running attacks against them.

### What's the difference between CAN1 and CAN2?

- **CAN1** is the trasnmitter, sends fake sensor data, and launches attacks
- **CAN2** is the listener, just watching traffic and updating device log

## Hardware Stuff

### Can I use a different microcontroller?

Short answer: not easily. The firmware is written for the Teensy 4.0. Teensy 4.1 would work with minor tweaks. Anything else? You're basically rewriting good portions of the code, but it is possible. Have fun with that.

### Why two CAN transceivers?

Each CAN interface needs its own transceiver to convert between Teensy logic levels and the differential signaling CAN uses. One per bus, no sharing.

### My display is blank / dead / showing nothing

Debug checklist:
1. Is it powered?
2. I2C wired right?
3. Right display? Firmware expects **SH1106**, not SSD1306. They look identical but aren't.
4. Still nothing? Run an I2C scanner sketch to see if anything responds at all.

### The buttons don't do anything

- Buttons should connect GPIO pin to ground when pressed
- Firmware uses internal pullups, so pressing = pin goes low
- Got a multimeter? Check if the button actually makes contact
- Check your solder joints. Cold joints are sneaky.

### Can I use different buttons or a display?

Code assumes:
- Active-low buttons (pressed = ground)
- SH1106 128x64 I2C OLED at address 0x3C

If you make changes to these then your milage may vary and you may have to update the code to reflect your changes.

## Protocol Stuff

### What NMEA2000 devices can NEMO see?

Anything transmitting on the bus. NEMO parses common PGNs and shows the data nicely. Unknown PGNs get dumped as hex—you can still see them, just gotta decode yourself.

The information received is also dumped out via serial so you can use other tools to process the data too!

### Why can't I impersonate some devices?

Impersonation only works for PGNs where the message structure has been defined in the code. Some proprietary or obscure PGNs aren't in there. PRs welcome if you reverse engineer more.

### Does NEMO support NMEA 0183?

Nope. Totally different protocol (serial ASCII sentences). NEMO only speaks NMEA2000/CAN. If you want 0183, you need different hardware.

### What baud rate?

250 kbps. That's the NMEA2000 standard. If your gear uses something else, it's not really NMEA2000.

## Attack Stuff

### How do I know if impersonation is working?

- The victim's display—values should change when you turn the pot
- Check serial output for debugging
- If nothing changes, make sure you're actually connected to the right network and the target device is receiving

### Can these attacks be detected?

Theoretically, yes. You could build an IDS that watches for:
- Spam-level address claim rates
- Multiple devices fighting over addresses
- Data that makes no physical sense (100mph wind speed, 10000ft depth)
- Timing patterns that don't match legit devices

In practice? Most marine gear has zero monitoring. It just trusts everything. That's... why we're here.

### Do these attacks work on all NMEA2000 networks?

The vulnerabilities are baked into the protocol spec, so yes, any compliant network is vulnerable. But real-world results vary:
- Some devices handle address conflicts weirdly
- Network topology matters—gotta be on the right segment
- Proprietary extensions might do unexpected things

Test it yourself. That's the fun part.

## Development Stuff

It's a bit scattered, but that's the pattern.

### Where do I find PGN documentation?

The official NMEA2000 appendix costs money. But:
- The NMEA2000 Arduino library has tons of definitions
- CANboat project has community-documented PGNs

### Can I contribute?

Open issues for bugs. PRs for new PGN support, fixes, or docs.

## Troubleshooting

### "Undefined reference" build errors

Library installation probably borked. Nuke the `.pio` folder and rebuild. Usually fixes it.

### Upload fails with "No Teensy detected"

- Is Teensy Loader running?
- Press the physical button on the Teensy to force bootloader mode
- Your USB cable might be charge-only (no data lines). Try a different one.
- Linux users: check your udev rules for Teensy

### Devices appear and disappear from the list

- Normal if devices transmit infrequently—some only send every few seconds
- "Stale Cleanup" in Device Config removes inactive devices after a minute
- Check for loose connections causing intermittent comms

### Sensor values don't change when I turn the pot

- Pot wired right? Middle pin goes to analog input
- Is the sensor set to Active?
- Is an attack running? Attacks use the pot differently

### My attack isn't doing anything

- Is CAN1 actually connected to the target network?
- Got termination on both ends?
- Can you see the target in Sensor Readings?
- Some devices take a while to notice they lost their address

## Safety & Legal

### Could this damage my equipment?

NEMO sends valid CAN messages. It can't fry your hardware through the protocol. However:
- Bad wiring can definitely damage things
- Attacks can make marine gear behave unexpectedly (that's the point)
- **Never** test on systems where malfunction could cause actual harm

### What if something goes wrong during an attack?

1. Stop the attack
2. Wait for devices to reclaim addresses
3. Power cycle anything acting weird
4. Disconnect NEMO, if needed

### Can I brick a device with these attacks?

Properly implemented NMEA2000 devices should recover just fine. But I can't guarantee every manufacturer got it right. Cheap/sketchy gear might behave unpredictably. Another reason why I take no responsibility for how you use this device.

### Is this legal?

Yes, testing in an approved setting, against approved hardware this device is legal (in America at least). If you start using this device on hardware you don't own or on boats you don't have permission to test on, the most likely answer is no. 

I take no responsibility for how you use the device.

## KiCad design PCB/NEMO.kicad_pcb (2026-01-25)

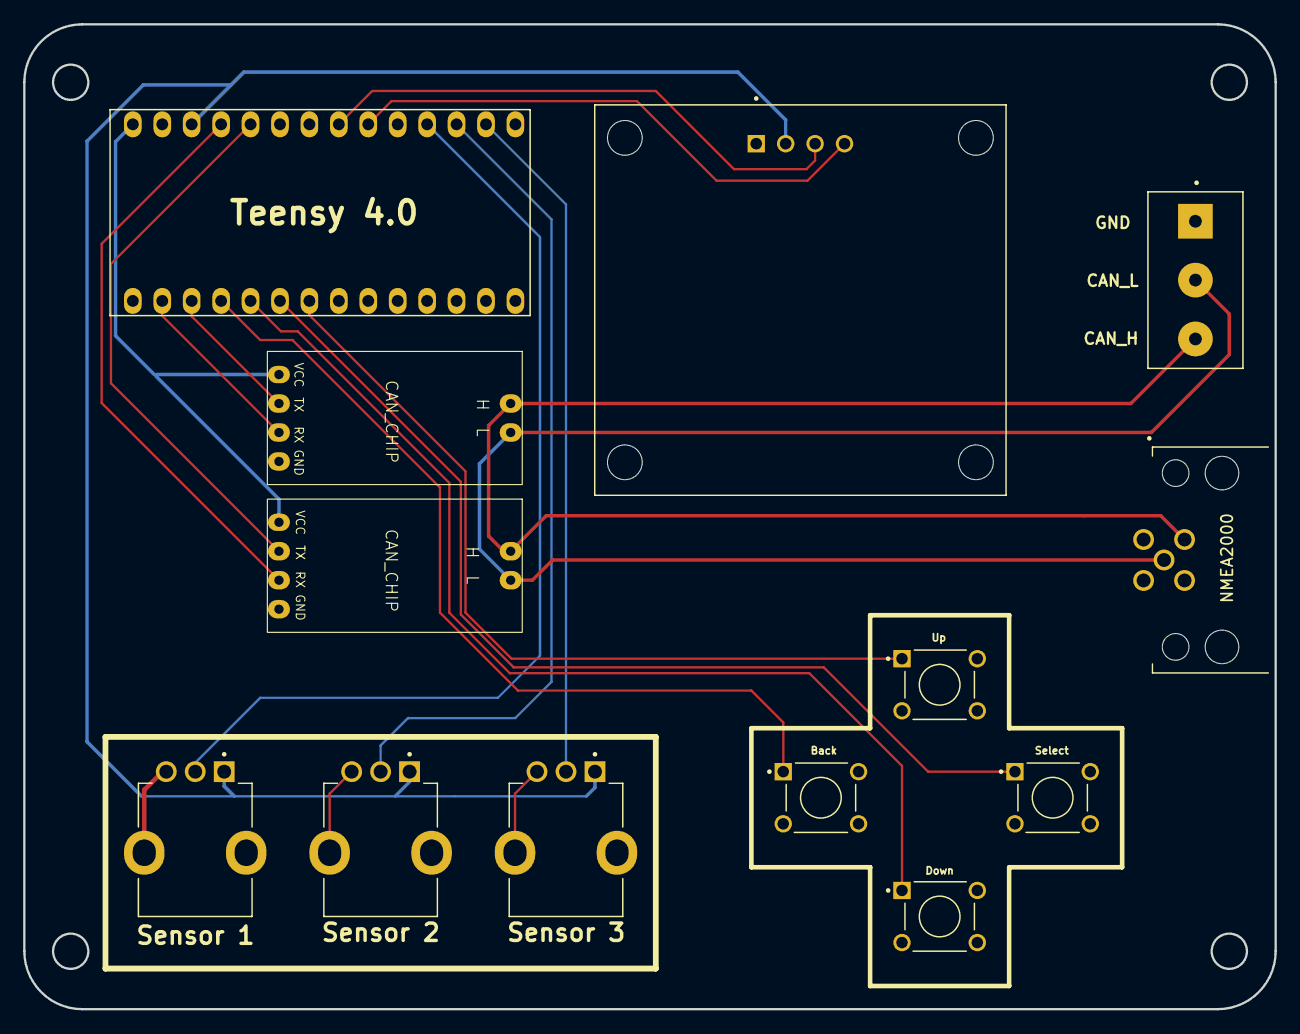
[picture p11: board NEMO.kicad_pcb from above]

Board: 2 copper layers, 108.0 x 85.0 mm, 13 parts (0 on the bottom side), 18 nets.

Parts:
Back: 1825910-6; SW_1825910-6-4
DS1: OLED_128X64_1.3_I2C; LCD_OLED_128X64_1.3_I2C
Down: 1825910-6; SW_1825910-6-4
J1: 282837-3; TE_282837-3
NMEA2000: 54-00387; NMEA2000
R1, R2, R3: RV09AF-40-20K-A10K; TRIM_RV09AF-40-20K-A10K
Select: 1825910-6; SW_1825910-6-4
Teensy 4.0: DEV-15583; MODULE_DEV-15583
U2, U3: CAN_CHIP
Up: 1825910-6; SW_1825910-6-4

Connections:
+3.3V: DS1.2 (VDD), R1.1, R2.1, R3.1, Teensy 4.0.3.3V_2
+5V: Teensy 4.0.VIN, U2.1 (VCC), U3.1 (VCC)
CAN_1_rx: Teensy 4.0.23, U2.3 (RX)
CAN_1_tx: Teensy 4.0.22, U2.2 (TX)
CAN_2_rx: Teensy 4.0.0, U3.3 (RX)
CAN_2_tx: Teensy 4.0.1, U3.2 (TX)
CAN_H: J1.3, NMEA2000.4, U2.5 (CAN_HI), U3.5 (CAN_HI)
CAN_L: J1.2, NMEA2000.5, U2.6 (CAN_LOW), U3.6 (CAN_LOW)
GND: Back.3, DS1.1 (GND), Down.3, J1.1, NMEA2000.3, R1.3, R1.SH1 (SHIELD), R1.SH2 (SHIELD), R2.3, R2.SH1 (SHIELD), R2.SH2 (SHIELD), R3.3, R3.SH1 (SHIELD), R3.SH2 (SHIELD), Select.3, Teensy 4.0.G1, Teensy 4.0.G3, U2.4 (GND), U3.4 (GND), Up.3
SCK: DS1.3 (SCK), Teensy 4.0.19
SDA: DS1.4 (SDA), Teensy 4.0.18
button_1: Select.1, Teensy 4.0.4
button_2: Teensy 4.0.5, Up.1
button_3: Down.1, Teensy 4.0.3
button_4: Back.1, Teensy 4.0.2
pot_1: R1.2, Teensy 4.0.16
pot_2: R2.2, Teensy 4.0.15
pot_3: R3.2, Teensy 4.0.14

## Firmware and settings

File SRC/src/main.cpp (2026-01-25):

/**
 * \file main.cpp
 * \brief Main entry point for NEMO (NMEA Educational Maritime Observatory) firmware.
 *
 *
 * The device uses two CAN interfaces:
 * - CAN1: Transmits simulated sensor data as multiple NMEA2000 devices
 * - CAN2: Listens to NMEA2000 traffic for monitoring and analysis
 *
 * \author Soups71
 
 */

#include<Arduino.h>
#include <NMEA2000.h>
#include <N2kMessages.h>
#include <NMEA2000_Teensyx.h>
#include "constants.h"
#include <PGN_Helpers.h>
#include <U8x8lib.h>
#include <U8g2lib.h>
#include <Menu.h>
#include <N2K_Monitor.h>
#include <Attack_Controller.h>
#include <Menu_Controller.h>
#include <Splash_Screen.h>
#include <Sensor.h>



//Primary CAN interface for transmitting simulated sensor data
tNMEA2000_Teensyx NMEA2000_CAN1(tNMEA2000_Teensyx::CAN1);

// Secondary CAN interface for listening to NMEA2000 traffic.
tNMEA2000_Teensyx NMEA2000_CAN2(tNMEA2000_Teensyx::CAN2);



//Interval in milliseconds between sensor updates.
#define UPDATE_INTERVAL 1000

//NMEA2000 manufacturer code for simulated devices.
#define DEVICE_MANUFACTURER_CODE 2046

//NMEA2000 device class for simulated devices.
#define DEVICE_CLASS 25

//Number of simulated devices on the NMEA2000 bus.
#define NUM_DEVICES 3

//Sequence counter for fast-packet frame fragmentation.
static uint8_t fastPacketSequence = 0;


//Timestamps of last button press for each button.
unsigned long lastButtonPress[4] = {0, 0, 0, 0};

//Debounce delay in milliseconds.
unsigned long debounceDelay = 250;

//Timestamp of last sensor update.
unsigned long lastUpdateTime = 0;

//Text-mode display driver for menu system.
U8X8_SH1106_128X64_NONAME_HW_I2C u8x8(/* reset=*/ U8X8_PIN_NONE);

// Graphics-mode display driver for splash screen.
U8G2_SH1106_128X64_NONAME_F_HW_I2C u8g2(U8G2_R0, /* reset=*/ U8X8_PIN_NONE);

//Simulated Engine RPM sensor (Device 0).
Sensor sensor1(SENSOR_PIN_1, MSG_ENGINE_RPM, &NMEA2000_CAN1, 0);

//Simulated Water Depth sensor (Device 1).
Sensor sensor2(SENSOR_PIN_2, MSG_WATER_DEPTH, &NMEA2000_CAN1, 1);

//Simulated Heading sensor (Device 2).
Sensor sensor3(SENSOR_PIN_3, MSG_HEADING, &NMEA2000_CAN1, 2);


//NMEA2000 network monitor instance
N2K_Monitor* n2kMonitor;

//Attack demonstration controller instance.
Attack_Controller* attackController;

//Menu system controller instance.
Menu_Controller* menuController;


/**
 * \brief Handles incoming NMEA2000 messages from CAN2 interface.
 * \param N2kMsg Reference to the received NMEA2000 message.
 */
void HandleNMEA2000Msg(const tN2kMsg &N2kMsg);


/**
 * \brief Configures the NMEA2000 CAN1 interface and simulated devices.
 */
void setupNMEA2000();


/**
 * \brief Prints a single CAN frame in candump format to Serial.
 * \param canId The 29-bit extended CAN identifier.
 * \param len The number of data bytes in the frame (0-8).
 * \param data Pointer to the array of data bytes.
 */
void PrintCanFrame(uint32_t canId, uint8_t len, const uint8_t *data);

/**
 * \brief Prints an NMEA2000 message in candump format, handling fast-packet fragmentation.
 * \param N2kMsg Reference to the NMEA2000 message to print.
 */
void PrintCandumpFormat(const tN2kMsg &N2kMsg);

/**
 * \brief Maps a button pin to its debounce array index.
 * \param button The button pin number (BUTTON_UP, BUTTON_DOWN, BUTTON_LEFT, or BUTTON_RIGHT).
 * \return The array index (0-3) corresponding to the button.
 */
int getButtonIndex(int button);

/**
 * \brief Checks if a button has been pressed with debounce filtering.
 * \param button The button pin number to check.
 * \return 1 if button is pressed and debounce time has elapsed, 0 otherwise.
 */
short buttonPressed(int button);



/**
 * \brief Arduino setup function - initializes all hardware and software components.
 *
 * This function is called once at startup and performs complete system
 * initialization:
 *
 * Hardware initialization:
 * - Serial communication at 115200 baud
 * - Sensor input pins (analog)
 * - Button input pins with internal pull-up resistors
 *
 * NMEA2000 initialization:
 * - CAN1 interface for sensor transmission (via setupNMEA2000())
 * - CAN2 interface for listening/monitoring
 *
 * Display initialization:
 * - Splash screen animation on startup
 * - OLED display for menu system
 *
 * Controller initialization:
 * - N2K_Monitor for NMEA2000 traffic analysis
 * - Attack_Controller for educational demonstrations
 * - Menu_Controller for user interface
 */
void setup(void)
{
  Serial.begin(115200);

  pinMode(SENSOR_PIN_1, INPUT);
  pinMode(SENSOR_PIN_2, INPUT);
  pinMode(SENSOR_PIN_3, INPUT);

  pinMode(BUTTON_UP, INPUT_PULLUP);
  pinMode(BUTTON_DOWN, INPUT_PULLUP);
  pinMode(BUTTON_LEFT, INPUT_PULLUP);
  pinMode(BUTTON_RIGHT, INPUT_PULLUP);

  setupNMEA2000();
  NMEA2000_CAN2.SetMsgHandler(HandleNMEA2000Msg);
  NMEA2000_CAN2.SetMode(tNMEA2000::N2km_ListenOnly);
  NMEA2000_CAN2.SetN2kCANReceiveFrameBufSize(2048);

  // Open both CAN interfaces
  NMEA2000_CAN2.Open();

  // Show splash screen animation
  Splash_Screen::show(&u8g2);

  // Initialize display for menu system
  u8x8.begin();
  u8x8.setPowerSave(0);

  // Initialize NMEA2000 Monitor
  n2kMonitor = new N2K_Monitor();

  // Initialize Attack Controller
  attackController = new Attack_Controller(&NMEA2000_CAN1, n2kMonitor, &sensor1);

  // Initialize Menu Controller
  menuController = new Menu_Controller(&u8x8,
                                      BUTTON_UP, BUTTON_DOWN,
                                      BUTTON_LEFT, BUTTON_RIGHT,
                                      &sensor1, &sensor2, &sensor3,
                                      n2kMonitor, attackController);
  menuController->begin();

#if DEBUG
  Serial.println("System initialized");
#endif
}

/**
 * \brief Arduino main loop - executes continuously after setup().
 *
 * This function implements the main program loop with the following
 * responsibilities:
 *
 * Sensor updates (every UPDATE_INTERVAL milliseconds):
 * - Normal operation: Update and transmit all sensor values
 * - Own-sensor impersonation: Continue normal transmissions alongside attack
 * - External attack: Only update sensor1 for potentiometer control
 *
 * CAN bus processing:
 * - Parse CAN1 messages (skipped during active attacks)
 * - Parse CAN2 messages for monitoring
 *
 * User interface:
 * - Update menu controller for real-time displays
 * - Process button inputs for navigation
 *
 * Button actions:
 * - UP: Navigate up in menu
 * - DOWN: Navigate down in menu
 * - LEFT: Navigate back/cancel
 * - RIGHT: Select/enter
 */

void loop(void)
{
  unsigned long currentTime = millis();

  // Update sensors at regular intervals
  if (currentTime - lastUpdateTime >= UPDATE_INTERVAL) {
    lastUpdateTime = currentTime;

    bool attackActive = attackController->isAttackActive();
    bool impersonatingOwn = attackController->isImpersonatingOwnSensor();

    if (!attackActive) {
      // Normal operation - update and send all sensors
      sensor1.update();
      sensor2.update();
      sensor3.update();

      // Send NMEA messages
      sensor1.sendMessage();
      sensor2.sendMessage();
      sensor3.sendMessage();

    } else if (impersonatingOwn) {
      // Impersonating own sensor - continue real transmissions for all sensors
      // This creates both real data (from sensors) and spoofed data (from attack)
      // User can see effect in Live Data with interleaved real/spoofed values
      sensor1.update();
      sensor2.update();
      sensor3.update();

      // Send messages from all sensors so Live Data shows real values
      sensor1.sendMessage();
      sensor2.sendMessage();
      sensor3.sendMessage();

    } else {
      // External attack (not impersonating own sensor) - only update sensor1 for potentiometer control
      sensor1.update();
    }
  }

  // Keep parsing both buses
  // Skip CAN1 parsing during attacks to prevent library from maintaining attack state
  if (!menuController->isAttackActive()) {
    NMEA2000_CAN1.ParseMessages();
  }
  NMEA2000_CAN2.ParseMessages();

  // Update menu controller (for real-time displays)
  menuController->update();

  // Handle button inputs
  if(buttonPressed(BUTTON_UP)){
    menuController->navigateUp();
  } else if(buttonPressed(BUTTON_DOWN)){
    menuController->navigateDown();
  } else if(buttonPressed(BUTTON_LEFT)){
    menuController->navigateBack();
  } else if(buttonPressed(BUTTON_RIGHT)){
    menuController->navigateSelect();
  }
}

void setupNMEA2000() {
  // Configure multi-device mode - each sensor appears as its own device on the bus
  NMEA2000_CAN1.SetDeviceCount(NUM_DEVICES);

  NMEA2000_CAN1.SetMode(tNMEA2000::N2km_NodeOnly, 22);

  // Set product info for all sensors BEFORE Open()
  // Use updateDeviceInfo() directly to avoid SendIsoAddressClaim before bus is open
  sensor1.updateDeviceInfo();
  sensor2.updateDeviceInfo();
  sensor3.updateDeviceInfo();

  // Now open - this will initialize the CAN bus
  NMEA2000_CAN1.Open();

  // Apply initial active/inactive state for each sensor
  // Sensors default to inactive, so set them to null address and disable heartbeat
  Sensor* sensors[] = {&sensor1, &sensor2, &sensor3};
  for (int i = 0; i < NUM_DEVICES; i++) {
    if (sensors[i]->isActive()) {
      // Active sensor - set custom name and broadcast info
      char name[20];
      snprintf(name, sizeof(name), "Sensor %d", i + 1);
      sensors[i]->setCustomName(name);
      delay(10);
      NMEA2000_CAN1.SendProductInformation(i);
      delay(10);
    } else {
      // Inactive sensor - set to null address (254) and disable heartbeat
      NMEA2000_CAN1.SetHeartbeatIntervalAndOffset(0, 0, i);
      NMEA2000_CAN1.SetN2kSource(254, i);  // Null address - removes from bus
    }
  }
}

void HandleNMEA2000Msg(const tN2kMsg &N2kMsg) {
#if !DEBUG
  // Print candump-style output for all received messages
  PrintCandumpFormat(N2kMsg);
#endif

  if(attackController != nullptr && attackController -> isSpamActive()) {
    attackController->attackHandler(N2kMsg);
  }
  // Handle incoming NMEA2000 messages directly
  if(n2kMonitor != nullptr && !attackController -> isSpamActive()) {
    n2kMonitor->handleN2kMessage(N2kMsg);
  }
}

short buttonPressed(int button){
  int idx = getButtonIndex(button);
  if(!digitalRead(button) && (millis() - lastButtonPress[idx]) > debounceDelay){
    lastButtonPress[idx] = millis();
    return 1;
  }else{
    return 0;
  }
}

int getButtonIndex(int button) {
  if (button == BUTTON_UP) return 0;
  if (button == BUTTON_DOWN) return 1;
  if (button == BUTTON_LEFT) return 2;
  if (button == BUTTON_RIGHT) return 3;
  return 0;
}

void PrintCandumpFormat(const tN2kMsg &N2kMsg) {
  // Reconstruct CAN ID: Priority (3 bits) | PGN (18 bits) | Source (8 bits)
  uint32_t canId = ((uint32_t)N2kMsg.Priority << 26) | ((uint32_t)N2kMsg.PGN << 8) | N2kMsg.Source;

  if (N2kMsg.DataLen <= 8) {
    // Single frame message - print directly
    PrintCanFrame(canId, N2kMsg.DataLen, N2kMsg.Data);
  } else {
    // Fast-packet message - re-fragment into 8-byte CAN frames
    uint8_t frame[8];
    int dataOffset = 0;
    int frameCount = 0;
    uint8_t seqId = (fastPacketSequence & 0x07) << 5;  // Sequence ID in upper 3 bits of counter byte

    while (dataOffset < N2kMsg.DataLen) {
      if (frameCount == 0) {
        // First frame: [SeqID + FrameNum] [TotalLen] [6 data bytes]
        frame[0] = seqId | (frameCount & 0x1F);
        frame[1] = N2kMsg.DataLen;
        int bytesToCopy = min(6, (int)N2kMsg.DataLen - dataOffset);
        for (int i = 0; i < bytesToCopy; i++) {
          frame[2 + i] = N2kMsg.Data[dataOffset + i];
        }
        // Pad remaining bytes with 0xFF
        for (int i = bytesToCopy; i < 6; i++) {
          frame[2 + i] = 0xFF;
        }
        dataOffset += bytesToCopy;
        PrintCanFrame(canId, 8, frame);
      } else {
        // Subsequent frames: [SeqID + FrameNum] [7 data bytes]
        frame[0] = seqId | (frameCount & 0x1F);
        int bytesToCopy = min(7, (int)N2kMsg.DataLen - dataOffset);
        for (int i = 0; i < bytesToCopy; i++) {
          frame[1 + i] = N2kMsg.Data[dataOffset + i];
        }
        // Pad remaining bytes with 0xFF
        for (int i = bytesToCopy; i < 7; i++) {
          frame[1 + i] = 0xFF;
        }
        dataOffset += bytesToCopy;
        PrintCanFrame(canId, 8, frame);
      }
      frameCount++;
    }

    fastPacketSequence++;
  }
}


void PrintCanFrame(uint32_t canId, uint8_t len, const uint8_t *data) {
  Serial.print("can1  ");
  if (canId < 0x10000000) Serial.print("0");
  if (canId < 0x1000000) Serial.print("0");
  if (canId < 0x100000) Serial.print("0");
  if (canId < 0x10000) Serial.print("0");
  if (canId < 0x1000) Serial.print("0");
  if (canId < 0x100) Serial.print("0");
  if (canId < 0x10) Serial.print("0");
  Serial.print(canId, HEX);

  Serial.print("   [");
  Serial.print(len);
  Serial.print("]  ");

  for (int i = 0; i < len; i++) {
    if (data[i] < 0x10) Serial.print("0");
    Serial.print(data[i], HEX);
    if (i < len - 1) Serial.print(" ");
  }
  Serial.println();
}

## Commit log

2026-01-25 First Release of NEMO
    [1825910-6.step, 282837-3.step, Bottom.stl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]
2026-02-17 Fix dead documentation links in README files
    All links in the root README.md were missing the Documentation/ prefix,
    causing them to 404 on GitHub. Also fixed a typo (PCB_Guide.md →
    PCB_Design.md) and removed a link to nonexistent CAN_Bus.md in
    Documentation/README.md.
